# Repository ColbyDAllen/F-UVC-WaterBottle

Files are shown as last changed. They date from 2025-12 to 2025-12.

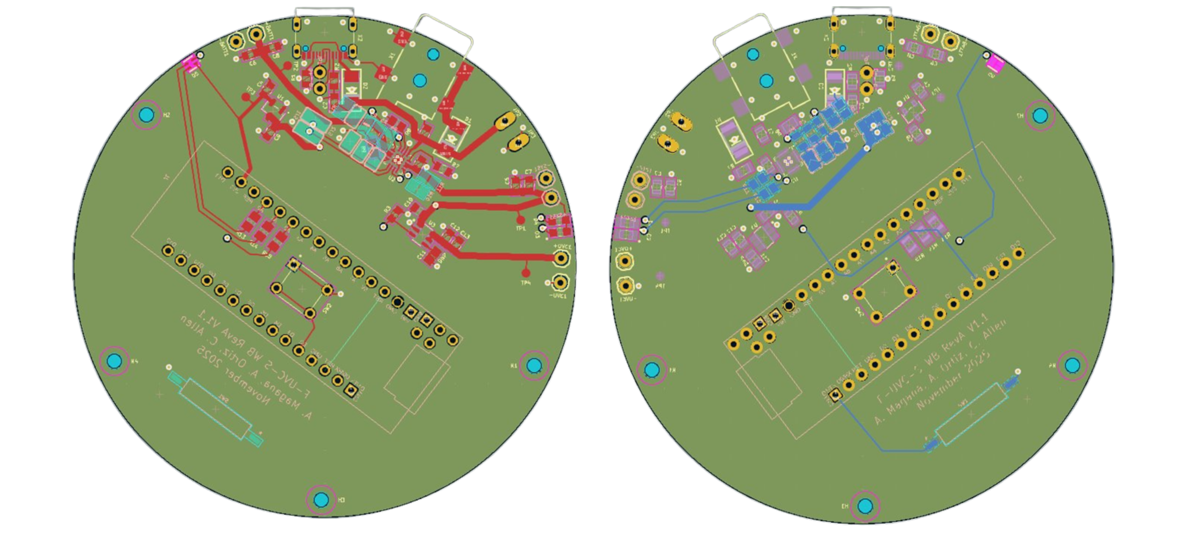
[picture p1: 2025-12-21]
Hardware/ECAD_v2/PCB_2D_ECAD.png

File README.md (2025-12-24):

# F-UVC-WaterBottle (Prototype)

**F-UVC-WaterBottle** is a prototype for a **portable, bottle-scale water treatment concept** that stages:

1. **Filtration** to handle turbidity and many dissolved contaminants, then  
2. **UVC LED exposure** to target microorganisms in the treated volume.

The current repo centers on **STM32 firmware** and a **lid PCB** that controls a gated UVC branch, backed by early **MCAD** for a two-chamber bottle (Outer dirty shell + inner filtered/UVC chamber) and a refillable filter cartridge.

> ⚠️ **Safety / Disclaimer**
>
> - This is **not** a certified disinfection device and **not** a minimum viable / usable product.  
> - **UVC is hazardous** to eyes and skin. Misuse can cause injury.  
> - Current printed parts are **not food-safe** and **not reliably watertight**.  
> - Battery-powered systems can fail dangerously if miswired (overcurrent, shorts, thermal runaway).  
> - This project exists for **engineering documentation and learning only**.  
>   **Do not rely on it for drinking water.**

---

## What this project is trying to explore

**User story (Target scenario)**

> “As someone who travels, camps, or works where tap water isn’t always viable,  
> I need a compact bottle that can handle **turbidity, taste, and biological contamination**,  
> so I can safely drink without hauling single-use filters, chemicals, or a stove.”

Rather than choosing **filtration *or* UVC**, this prototype explores a **staged approach** inspired by:

- **Press-to-filter systems** (e.g. Grayl GeoPress) for **multi-barrier filtration**, and  
- **Cap-integrated UVC** (e.g. Larq PureVis 2) for **in-bottle optical disinfection**.

The long-term research question is:  

Can a bottle-scale system combine **filter-first** architecture with **geometry-aware UVC dosing** and still be **usable** (Cycle times, charging, cleaning, and cost)?

For the full background, math, and validation plan, see the accompanying [project write-up](https://colbydanielallen.com/portfolio/filtration-uvc-water-bottle/).

---

## Repository layout

- **/Software/** – STM32L031 firmware project (STM32CubeIDE)  
- **/Hardware/** – hardware artifacts  
  - **/Hardware/ECAD/** – KiCad PCB files for the lid/control board (power path, MCU, interlocks, UVC gating)  
  - **/Hardware/MCAD/** – SolidWorks models & STEP files for the bottle's inner chamber, outer chamber, lid, and filter cartridge  
- **/Docs/** *(planned)* – validation notes, test logs, and design references

---

## System overview

### Functional architecture

**Treatment path**

1. **Outer chamber (Dirty water)**  
   - Filled from the source (Tap, stream, questionable faucet).  
   - Houses a **threaded, refillable filter cartridge**.

2. **Filter cartridge (FairCap-inspired)**  
   - Printable shell intended to be packed with **cotton + activated carbon + media**.  
   - Goal: Reduce particulates, some metals/organics, and improve UV transmittance (UVT).

3. **Inner chamber (Filtered water)**  
   - Receives water through the filter cartridge.  
   - Interior will be designed to be **reflective** and geometrically favorable for UVC dose delivery.

4. **Lid UVC subsystem**  
   - Contains **UVC LED + driver**, **charger/power-path board**, **MCU**, **load switch**, **reed switch**, and **status LED(s)**.  
   - UVC LED shines through a **small UVC-transmissive window** into the inner chamber.

**Electronics & control**

- **Li-ion battery** + **BQ24074-class charger** for USB/DC/solar input and load sharing.  
- **3.3 V rail** for logic (STM32L031K6).  
- **High-side load switch** for the UVC branch (Gated by MCU and interlocks).  
- **Single push button** for cycle control.  
- **RGB LED** for state indication.  
- **Reed switch + magnet** for lid-closed detection (firmware + hardware gating).

---

## Hardware stack

### MCAD (Bottle chambers, lid, and filter)

The MCAD branch (SolidWorks) currently includes:

- **Outer chamber**: Holds untreated water.  
- **Inner chamber**: Receives filtered water and forms the UVC treatment volume.  
- **Filter cartridge**: A threaded, refillable block inspired by FairCap, intended to be packed with media (cotton + activated carbon + salt, etc.).  
- **Lid**: Houses the electronics, UVC lens/window, RGB light pipes, and reed-switch magnet pocket.

**Status / caveats**

- Current prints are **PETG** and intended as **“looks-like” prototypes only**.  
- Magnet pocket and wall thickness are still being refined (Early prints exposed the magnet cavity into the threads).  
- Future revisions will move away from epoxy and toward **M2 fasteners and gaskets** for serviceability and sealing.  
- Long-term, a **metal inner chamber** (Steel) would be preferable for UVC compatibility and cleanliness.

### ECAD (Lid PCB, rev A)

The ECAD branch uses **KiCad** and currently implements:

- **Power path & charging**
  - **BQ24074-class charger** (Adafruit reference design)  
  - Input: **USB-C or solar (5-10 V)**  
  - Load sharing (Run from input while charging battery)  
  - Input dynamic power management to avoid solar brown-out  
  - Status: **PGOOD**, **CHG** exposed for future MCU use

- **Logic rail**
  - **MCP1700** 3.3 V LDO (or similar) from charger **SYS/OUT** rail  
  - Local decoupling and layout tuned for stability

- **UVC branch gating**
  - **TPS22918** high-side load switch
  - VIN from SYS rail, VOUT to UVC driver module  
  - MCU-controlled **EN**, default-OFF on reset/boot  
  - Optional CT pin for soft-start (In-rush shaping)

- **MCU & I/O**
  - **STM32L031K6**: Initially hosted on a **NUCLEO-L031K6** dev board, with the custom PCB providing power and I/O connectivity.  
  - **Reed switch**: Input for lid-closed detection.  
  - **Single user button**: User input.  
  - **RGB LED** (tri-color, PWM-driven): For state indication.

A separate constant-current UVC LED board (i.e. **IO Rodeo 275nm module**) currently handles LED drive. In future revisions its topology could be folded into a dedicated UVC daughterboard or an integrated lid PCB.

---

## Firmware: STM32L031K6

Firmware lives under **`/Software/`** and targets **STM32L031K6Tx**, typically on a **NUCLEO-L031K6** for bring-up.

### High-level behavior

- **Gated UVC branch**
  - Controls the UVC load-switch **EN** line.  
  - **OFF by default** at boot/reset.  
  - Forced OFF on:
    - lid-open (reed switch)  
    - cycle cancel  
    - (future) fault conditions

- **Cycle selection (single button)**
  - **Single tap** → short cycle (~1 minute), LED **amber** (R+G).  
  - **Double tap** (within ~400 ms) → long cycle (~3 minutes), LED **blue**.  
  - **Tap during an active cycle** → cancel cycle, force UVC OFF, return to idle.

- **Reed-switch safety**
  - Input is configured with pull-up:
    - **LOW → lid closed / magnet present (safe)**  
    - **HIGH → lid open (unsafe → force UVC OFF)**  
  - If lid opens during a cycle:
    - UVC branch is shut off immediately.  
    - State machine resets (no lingering taps or modes).  
    - LED returns to idle (off).

- **Auto-stop**
  - Each cycle tracks a target end-time.  
  - At expiry, UVC branch = OFF, mode cleared, LED back to idle.

### I/O mapping (expected)

**Inputs**

- `REED_SW_Pin` – reed switch (input with pull-up).  
- `B2_Pin` – user button (EXTI, falling-edge, active-low).

**Outputs**

- `Control_Pin` – UVC load-switch enable:  
  - LOW → UVC branch OFF  
  - HIGH → UVC branch ON
- RGB LED via **TIM2 PWM** channels (common-anode assumed):
  - `PA3` → TIM2 CH4 → RED  
  - `PA1` → TIM2 CH2 → GREEN  
  - `PA0` → TIM2 CH1 → BLUE

Some SPI/OLED-related pins may remain configured from CubeMX templates. They’re reserved for future debug UI and don’t affect UVC logic.

---

## Build & flash (STM32CubeIDE)

- **Toolchain:** STM32CubeIDE 
- **Target MCU:** STM32L031K6Tx

1. Clone the repository.
2. Open **STM32CubeIDE** → **File → Import… → Existing Projects into Workspace…**.
3. Select the firmware project under `/Software/`.
4. Build the **Debug** or **Release** configuration.
5. Connect **ST-LINK** (NUCLEO onboard or external).
6. Click **Run** or **Debug** to flash.

After flashing, for bench testing:

- Power the board from a **regulated 3.3 V rail** (or the NUCLEO’s default power path).  
- Connect the reed switch, button, RGB LED, and load-switch control line as per the I/O mapping.  
- Confirm that behavior matches the “High-level behavior” section above using a **safe stand-in load** (e.g. an OLED display or resistor) instead of a UVC LED.

---

## Validation status (UVC effectiveness)

A detailed **biodosimetry-based validation plan** is drafted (MS2 coliphage, collimated-beam-derived k(λ), RED/VF framework, EPA 186 mJ/cm² target), but:

> 🔬 **No biological tests have been executed yet.**  
> No log-reduction claims are made for this prototype.

Until validation is complete:

- All cycle times, UX modes, and design equations should be treated as **engineering placeholders**, not safety guarantees.  
- Any use of this design with real water is strictly **at your own risk** and **strongly discouraged**.

---
## Sponsorship (PCB fabrication)

<p align="center">
  PCBWay Sponsorship
</p>

F-UVC cap PCB – top side

PCB fabrication for this prototype was kindly sponsored by
[PCBWay](https://www.pcbway.com/), who covered the cost of the
4-layer boards and DHL shipping via store credit.

From a bring-up perspective the experience was exactly what I was hoping for:

- The 4-layer FR-4 S1000H TG150 stack-up (78 × 78 mm, 1.6 mm, ENIG, 1 oz Cu inner/outer)
  matched the KiCad design with no surprises.
- Drill hits, solder mask, and silkscreen registration were all on-point; pads were fully
  exposed and silkscreen stayed off fine-pitch pads.
- ENIG pads wetted cleanly during hot-air/QFN reflow, and the USB-C, BQ24074, and header
  footprints all fit mechanically without any bodge-wires or footprint hacks.

This repository and write-up reflect my own design decisions, testing, and documentation.
Sponsorship support did not include editorial control or performance claims; any results
here are based on my own prototyping and are shared for transparency and learning.

---

## Roadmap / next steps (WIP)

Planned expansions to this repo:

- **ECAD**
  - Integrate or document a dedicated UVC LED + heatsink board.  
  - Tighten power-integrity checks (inrush, brownout behavior, EMC, thermal).

- **MCAD**
  - Add outer bottle, finalized filter cartridge, and realistic sealing strategy (O-rings, glands/grooves, fasteners).  
  - Explore food-safe materials (Metal inner chamber, UVC-stable windows, and gaskets).

- **Firmware**
  - Add explicit **fault/error states** (Blink codes, fault latch, charging/solar status UI).  
  - Integrate charger status (PGOOD / CHG) into UX.

- **Testing & validation**
  - Execute **UVC biodosimetry tests** and publish RED / DVal results.  
  - Map measured performance back into Design Equations 1 & 2 to tune cycle times and power.

---

## License

MIT License — see `LICENSE`.

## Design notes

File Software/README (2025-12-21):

This firmware is part of a UVC water disinfection prototype. 

UVC light can be hazardous to skin and eyes. 

Do not operate any UVC LEDs without proper enclosure, shielding, and safety testing. 

This code is provided for educational and prototyping purposes only.

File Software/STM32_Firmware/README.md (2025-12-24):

# F-UVC Water Bottle – STM32L031 Firmware

Firmware for a prototype UVC water bottle controller built around an **STM32L031K6** MCU (typically on a **NUCLEO-L031K6** dev board or an equivalent custom PCB).

> ⚠️ **Safety warning – read first**
>
> - This firmware is part of a **UV-C water disinfection prototype**.
> - UV-C is hazardous to **eyes and skin**.
> - Do **not** power any UV-C LEDs without a proper enclosure, interlocks, and safety testing.
> - This code is provided for **educational and prototyping** purposes only. Do **not** rely on it to produce safe drinking water.

---

## Behavior (user-facing)

The firmware implements a simple tap-based UI and a lid interlock:

- **Single tap** on the button  
  - Starts a **short UV-C cycle (~1 minute)**  
  - UV-C load switch is **enabled**  
  - RGB status LED shows **amber** (R + G)

- **Double tap** (two taps within ~400 ms)  
  - Starts a **long UV-C cycle (~3 minutes)**  
  - UV-C load switch is **enabled**  
  - RGB status LED shows **blue**

- **Tap during an active cycle**  
  - **Cancels** the current cycle immediately  
  - UV-C load switch turns **OFF**  
  - RGB LED returns to **idle (off)**

- **Lid safety (reed switch interlock)**  
  - Reed switch is wired so **LOW = lid closed / magnet present (safe)**  
  - **HIGH = lid open (unsafe)**  
  - If the firmware ever detects **lid open** while a cycle is active, it will:
    - Turn the UV-C load switch **OFF**
    - **Abort** the running cycle
    - Clear any pending tap state
    - Block new cycles until the lid is closed again (reed back LOW)

---

## Hardware assumptions (logical)

This firmware expects a hardware stack roughly matching:

- **MCU**: STM32L031K6 (NUCLEO-L031K6 or equivalent custom board)
- **UV-C branch**: UV-C LED driver powered through a **high-side load switch**
- **Lid interlock**: **reed switch + magnet** detecting lid-closed state
- **UI**:  
  - 1 × **momentary push button** (active-low, interrupt-driven)  
  - 1 × **RGB LED** driven from TIM2 PWM channels

Exact pin names (e.g., `REED_SW_Pin`, `B2_Pin`, `Control_Pin`, RGB LED pins) are defined in the CubeMX-generated project and should be kept in sync with your hardware.

---

## Build & flash (STM32CubeIDE)

**Toolchain:** STM32CubeIDE  
**Target:** STM32L031K6Tx

1. Clone the repository and navigate to the `Software/` directory.
2. In **STM32CubeIDE**, go to  
   `File → Import… → Existing Projects into Workspace…`
3. Select the `Software` folder (or the STM32 project folder inside it) as the **root directory**.
4. Import the project and build the **Debug** (or **Release**) configuration.
5. Connect a **NUCLEO-L031K6** (onboard ST-LINK) or an external ST-LINK to your custom board.
6. Use the provided **Debug/Run configuration** (or create your own) to flash the firmware.

This project uses the **STM32 HAL** and the CubeMX-generated linker script  
`STM32L031K6TX_FLASH.ld`.

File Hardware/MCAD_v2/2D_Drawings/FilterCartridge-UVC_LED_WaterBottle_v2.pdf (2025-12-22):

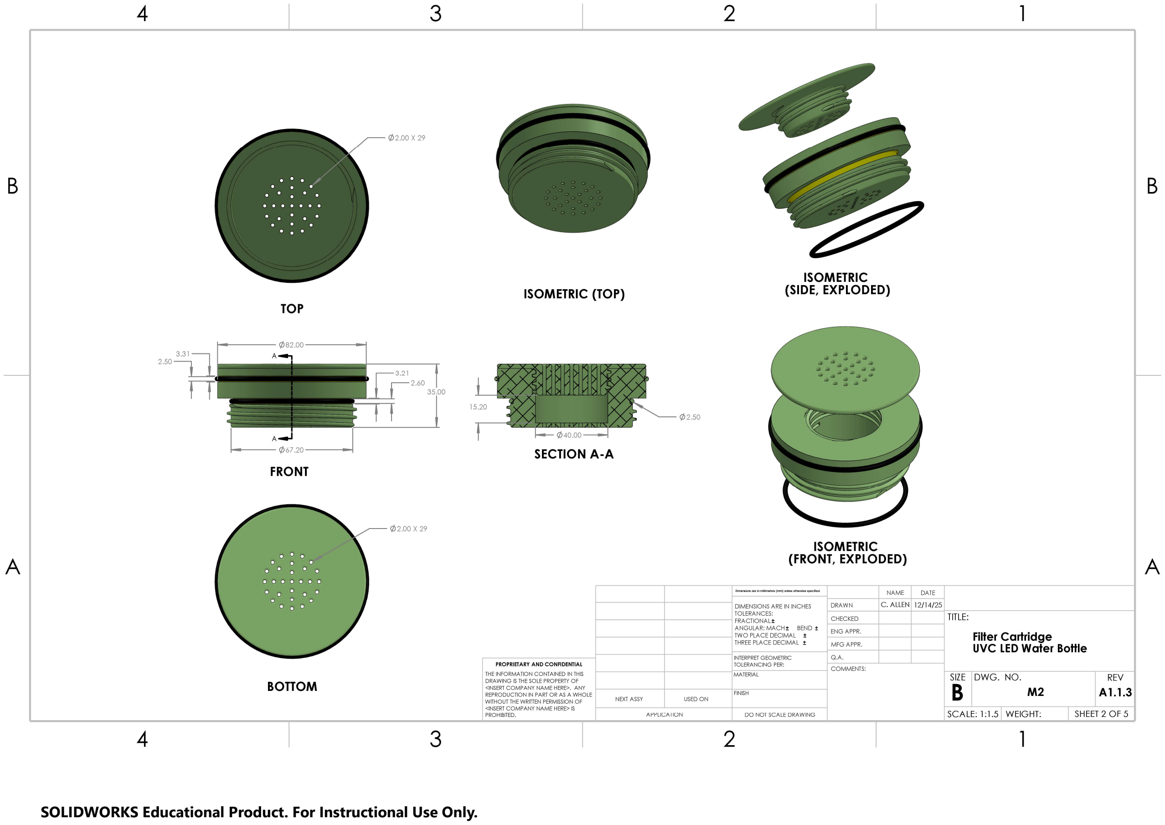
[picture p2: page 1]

SOLIDWORKS Educational Product. For Instructional Use Only.

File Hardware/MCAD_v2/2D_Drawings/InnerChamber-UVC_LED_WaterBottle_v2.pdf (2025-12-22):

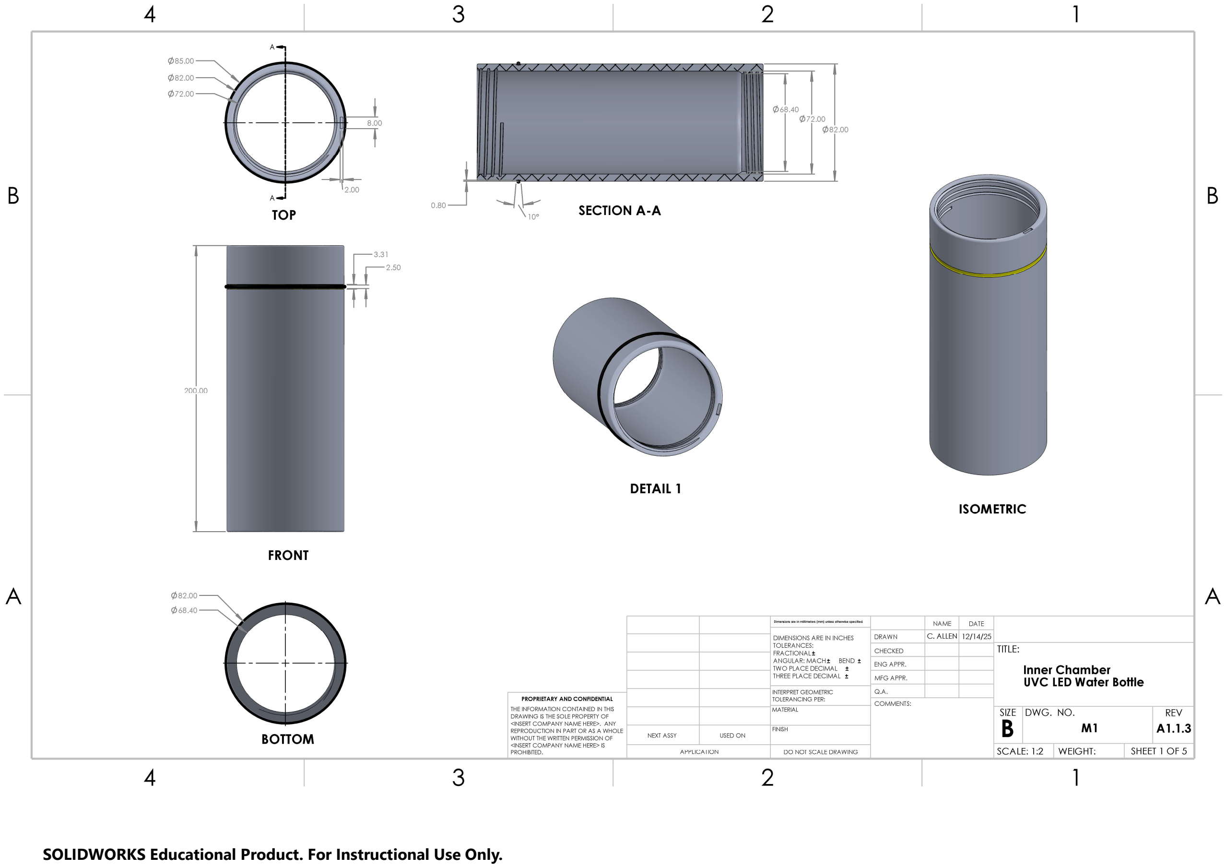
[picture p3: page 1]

SOLIDWORKS Educational Product. For Instructional Use Only.

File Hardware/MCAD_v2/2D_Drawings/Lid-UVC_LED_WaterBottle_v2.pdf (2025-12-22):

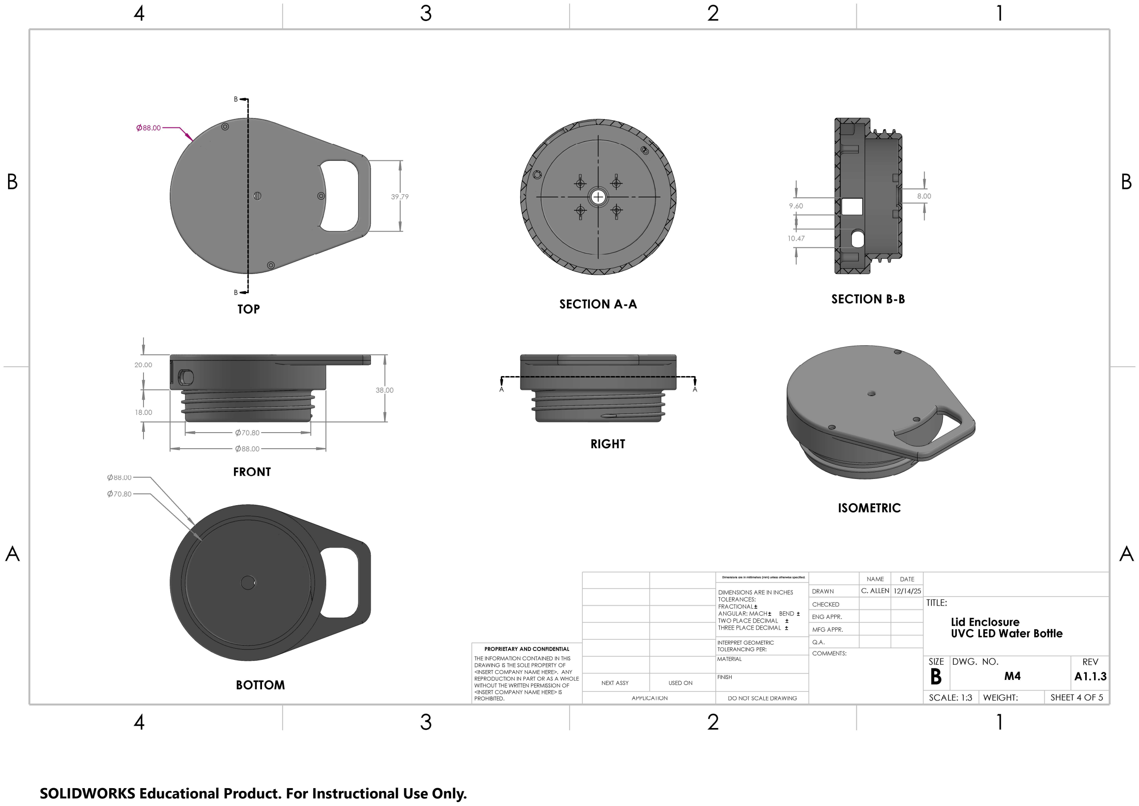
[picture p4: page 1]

SOLIDWORKS Educational Product. For Instructional Use Only.

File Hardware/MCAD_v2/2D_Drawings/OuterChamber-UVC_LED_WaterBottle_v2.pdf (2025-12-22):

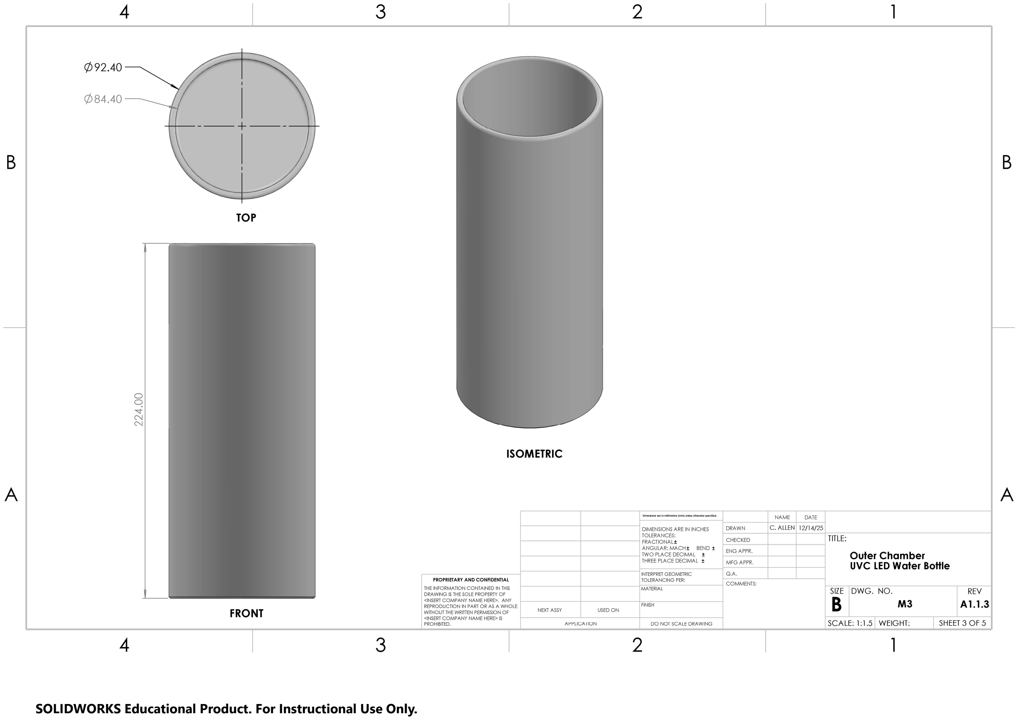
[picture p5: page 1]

SOLIDWORKS Educational Product. For Instructional Use Only.

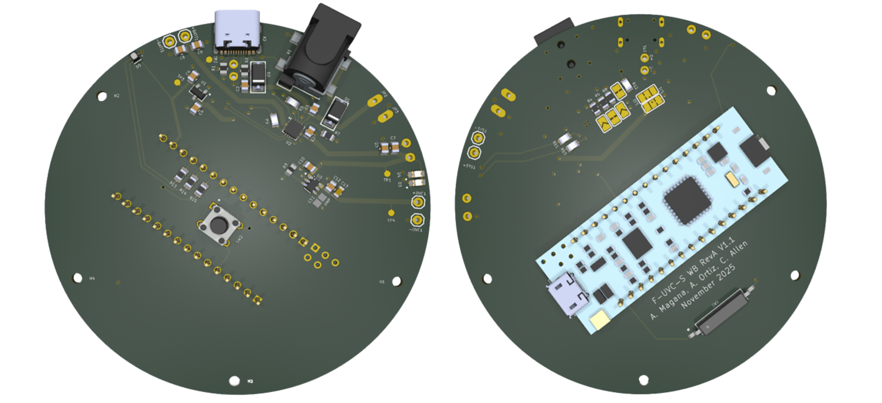
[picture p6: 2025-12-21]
Hardware/ECAD_v2/PCB_3D_ECAD.png

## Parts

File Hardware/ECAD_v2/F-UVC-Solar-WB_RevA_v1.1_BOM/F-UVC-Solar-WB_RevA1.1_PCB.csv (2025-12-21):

Id | Designator | Footprint | Quantity | Designation | Supplier and ref
1 | R9,R8,R12,R10,R11 | RES_10k_0805 | 5 | 10K
2 | R15,R14,R13 | RES_2.2K_0805 | 3 | 2.2K
3 | D2,D1 | SMADIODE | 2 | SK34A
4 | SW2 | SW_Push_6mm_Tall_SW_TS02-66-100-BK-260-LCR-D | 1 | TS02-66-100-BK-260-LCR-D
5 | U2 | BQ24074_QFN16_3MM | 1 | BQ24074
6 | -UVC1,+BATT1,+UVC1,-BATT1,-SYS1,+SYS1 | 1X01_BatteryTerminal_HandSolder | 6 | ~
7 | R7,R5 | RES_1k_0805 | 2 | 1K
8 | C9,C3,C7,C5,C1,C4,C6,C2,C8 | CAP_10uF_0805(CAP_CL21_SAM) | 9 | 10 uF
9 | JP1 | 1X02_ROUND | 1 | HEADER-1X2ROUND
10 | D5 | LED_RGB_DIFFUSED_0606_150161M153130 | 1 | LED_RGB_DIFFUSED_0606_150161M153130
11 | U3 | TPS22918TDBVRQ1_SOT95P280X145-6N | 1 | TPS22918TDBVRQ1
12 | C11 | CAP_470pF_0805 | 1 | 470 pF
13 | R3 | RES_100k_0805(RC0805N_PAN) | 1 | 100K
14 | TP3 | TestPoint_PAD.03X.05 | 1 | +3V3(TP)
15 | X2 | USB_C_CUSB31-CFM2AX-01-X | 1 | USB Type C
16 | C10 | CAP_1uF_0805 | 1 | 10 uF
17 | U1 | MCP1700T_3302E_TT(SOT-23_MC_MCH( | 1 | MCP1700T-3302E/TT
18 | TP1 | TestPoint_PAD.03X.05 | 1 | OUT(TP)
19 | C12 | CAP_10uF_0805(CAP_CL21_SAM) | 1 | 1 uF
20 | X1 | DCJACK_2MM_SMT | 1 | 2.1mm DC
21 | D4 | LED_RED_0805(HSMC_C170) | 1 | RED
22 | D3 | LED_RED_0805(HSMC_C170) | 1 | GREEN
23 | JP3,JP2 | 1X01_OVAL | 2 | HEADER-1X1
24 | C13 | CAP_10uF_0805(CAP_CL21_SAM) | 1 | 0.1 uF
25 | TP2 | TestPoint_PAD.03X.05 | 1 | VLIPO(TP)
26 | R2,R1 | RES_5.1k_0805 | 2 | 5.1K
27 | TP4 | TestPoint_PAD.03X.05 | 1 | VLOAD(TP)
28 | UNK1A1,THERM1 | SOLDERJUMPER_CLOSEDWIRE | 2 | SOLDERJUMPERCLOSED
29 | R6 | RES_2k_0603 | 1 | 2k
30 | UNK0.5A1,UNK1.5A1 | SOLDERJUMPER_ARROW_NOPASTE | 2 | SOLDERJUMPER
31 | SW1 | ReedSwitch_CT10-1530-G1 | 1 | SW_Reed
32 | SJ1,SJ2 | SOLDERJUMPER_2WAY_OPEN_NOPASTE | 2 | ~
33 | R4 | RES_590_0805 | 1 | 590
34 | J1 | NUCLEO-L031K6 | 1 | Header 15X1_male

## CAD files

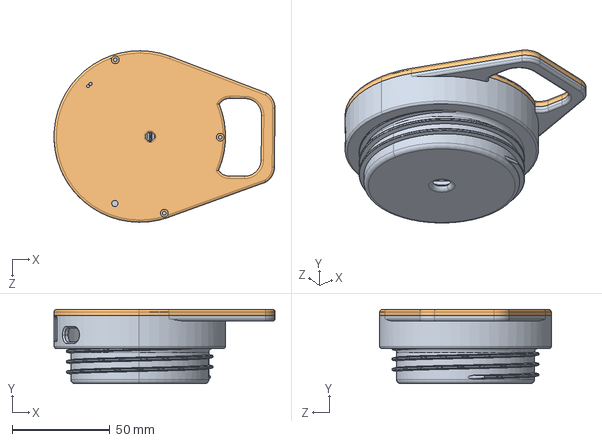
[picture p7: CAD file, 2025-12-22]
Hardware/MCAD_v2/Print_Files/Lid-UVC_LED_WaterBottle_v2.STEP
113.3 x 38.0 x 88.0 mm

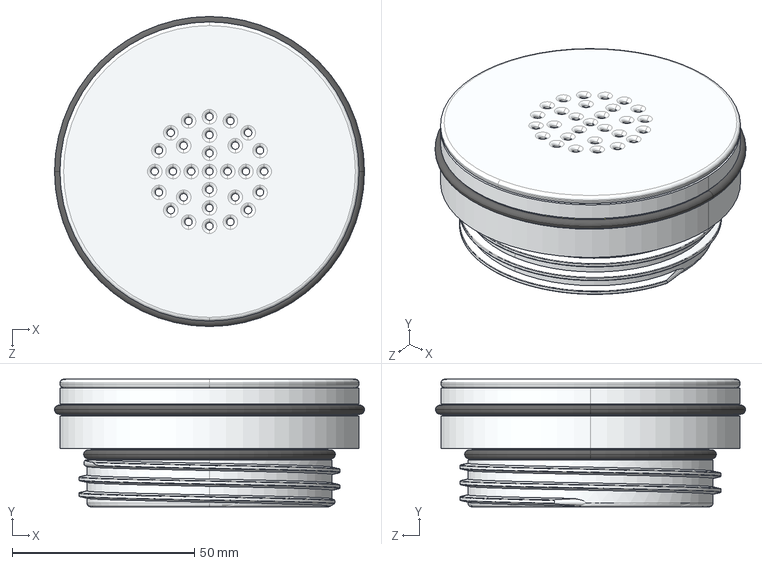
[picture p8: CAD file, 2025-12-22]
Hardware/MCAD_v2/Print_Files/FilterCartidge-UVC_LED_WaterBottle_v2.STEP
85.0 x 35.0 x 85.0 mm

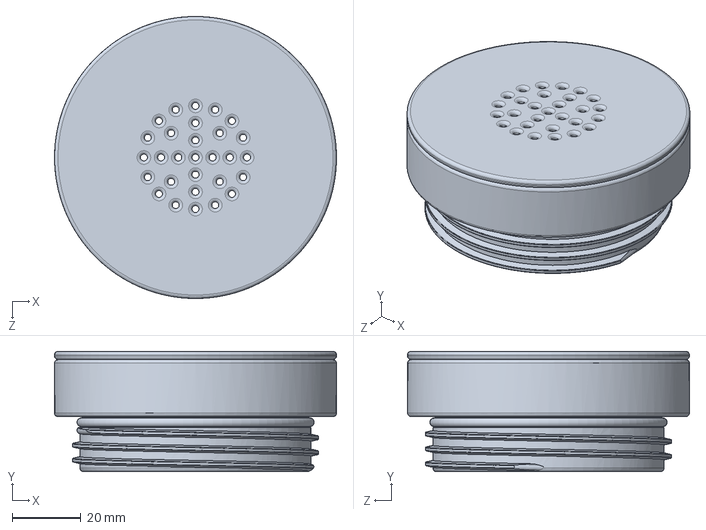
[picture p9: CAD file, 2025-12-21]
Hardware/MCAD_v2/SolidWorks_Files/F-UVC-Solar_RevA1.1.3_FilterCartridge.SLDPRT
82.0 x 35.0 x 82.0 mm

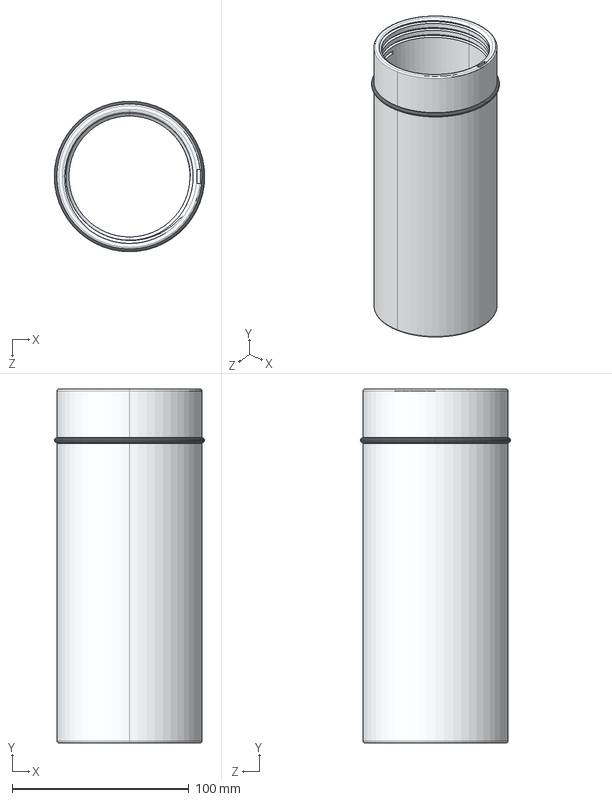
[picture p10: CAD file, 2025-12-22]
Hardware/MCAD_v2/Print_Files/InnerChamber-UVC_LED_WaterBottle_v2.STEP
85.0 x 200.0 x 85.0 mm

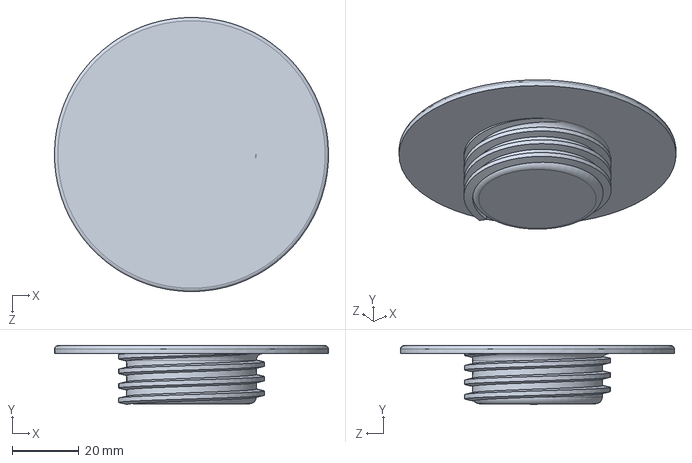
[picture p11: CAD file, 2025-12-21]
Hardware/MCAD_v2/SolidWorks_Files/F-UVC-Solar_RevA1.1.3_FilterCartridgeBottom_COMBINE.SLDPRT
82.0 x 17.7 x 82.0 mm

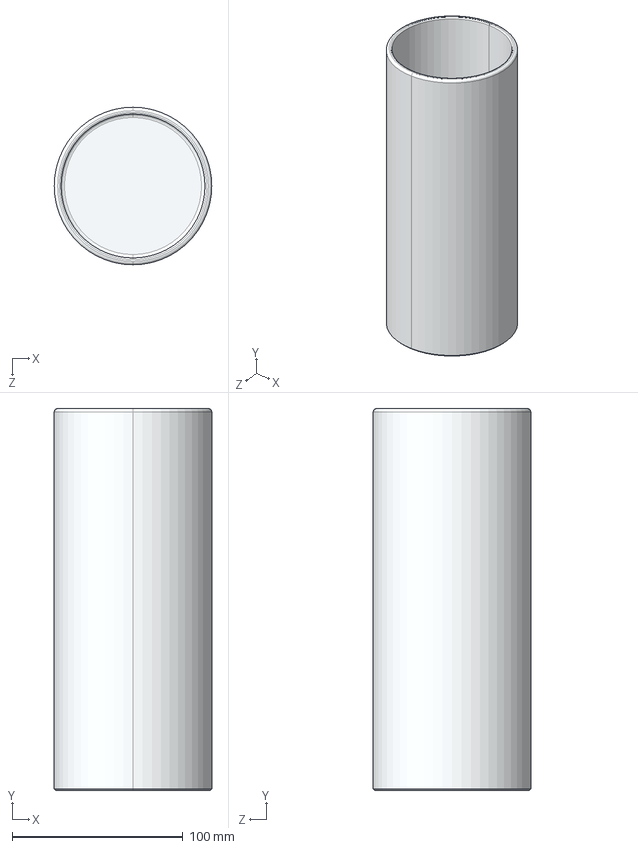
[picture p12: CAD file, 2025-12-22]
Hardware/MCAD_v2/Print_Files/OuterChamber-UVC_LED_WaterBottle_v2.STEP
92.4 x 224.0 x 92.4 mm

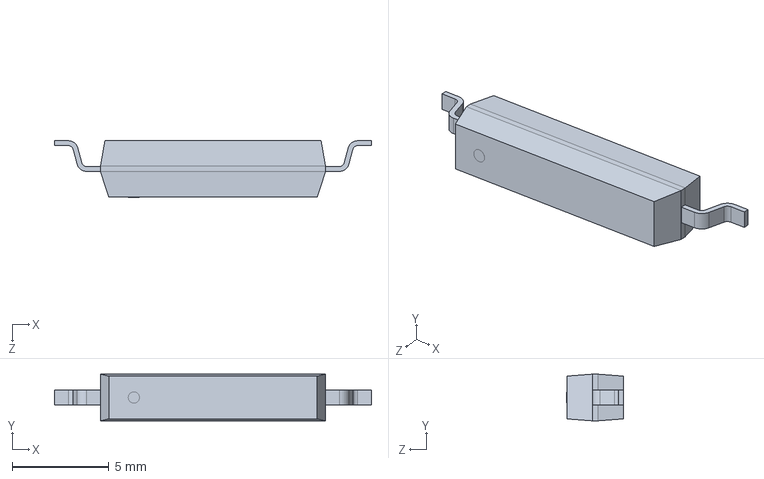
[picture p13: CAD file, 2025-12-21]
Hardware/MCAD_v2/SolidWorks_Files/SW_CT10-xxxx-G1_COT_2.SLDPRT
16.4 x 2.41 x 2.92 mm

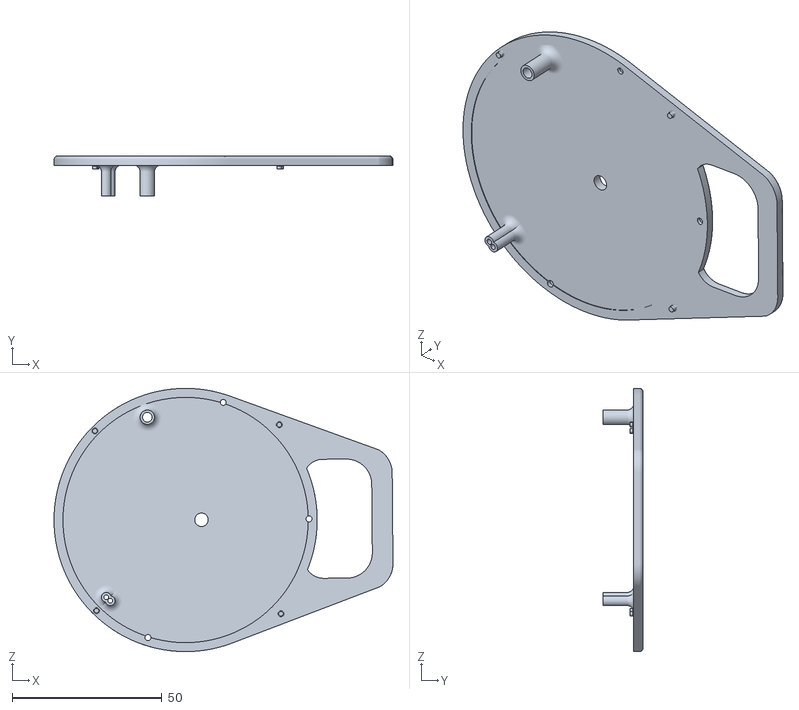
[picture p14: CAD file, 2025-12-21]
Hardware/MCAD_v2/Print_Files/LidTop-UVC_LED_WaterBottle_v2.STL
113.3 x 13.4 x 88.0

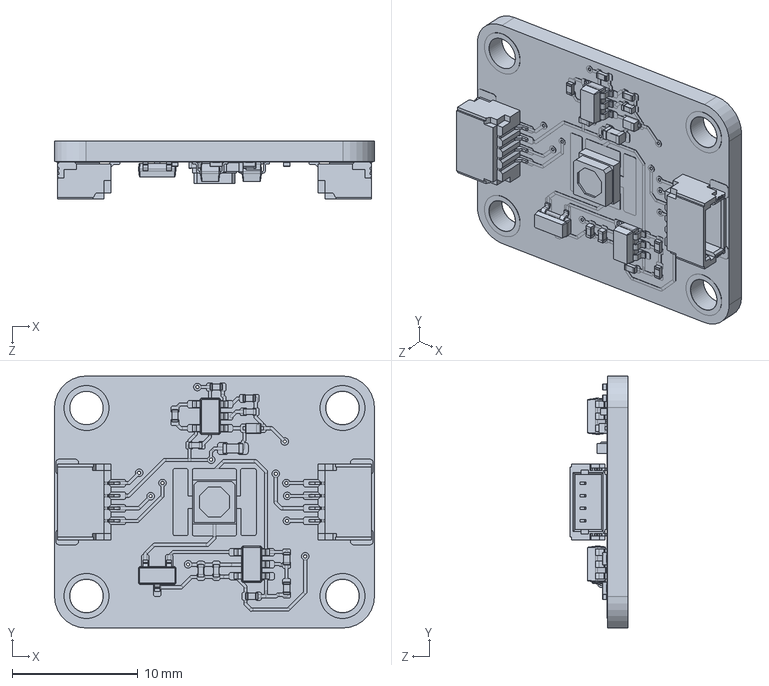
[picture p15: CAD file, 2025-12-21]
Hardware/MCAD_v2/SolidWorks_Files/275nm_SU_CULBN2_24mA_2.SLDPRT
25.4 x 20.0 x 4.64 mm

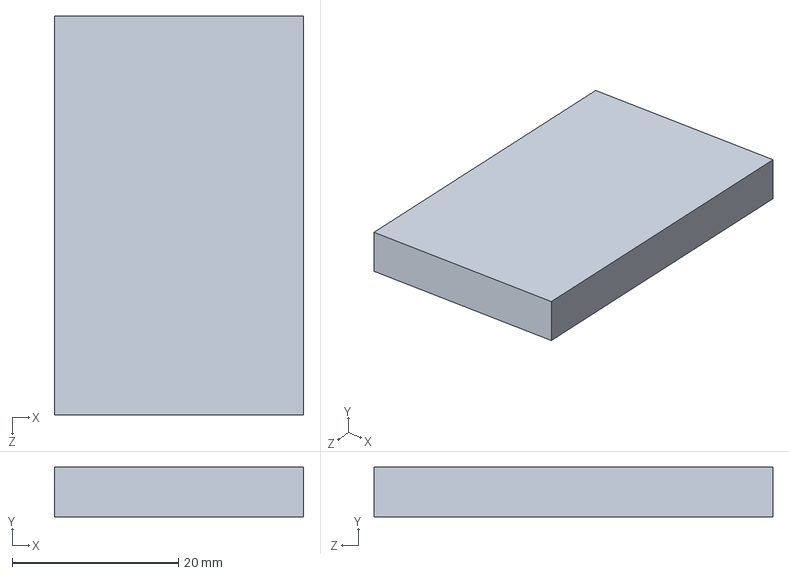
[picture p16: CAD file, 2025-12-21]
Hardware/MCAD_v2/SolidWorks_Files/850mAh,3.7v_2.SLDPRT
30.0 x 6.00 x 48.0 mm

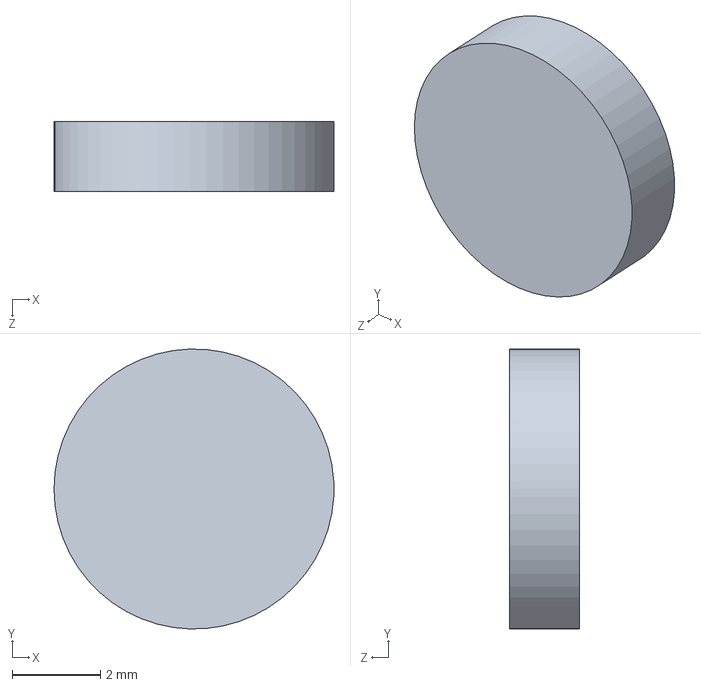
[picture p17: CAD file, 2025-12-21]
Hardware/MCAD_v2/SolidWorks_Files/Neodymium Iron Boron Magnet_2.SLDPRT
6.35 x 6.35 x 1.59 mm

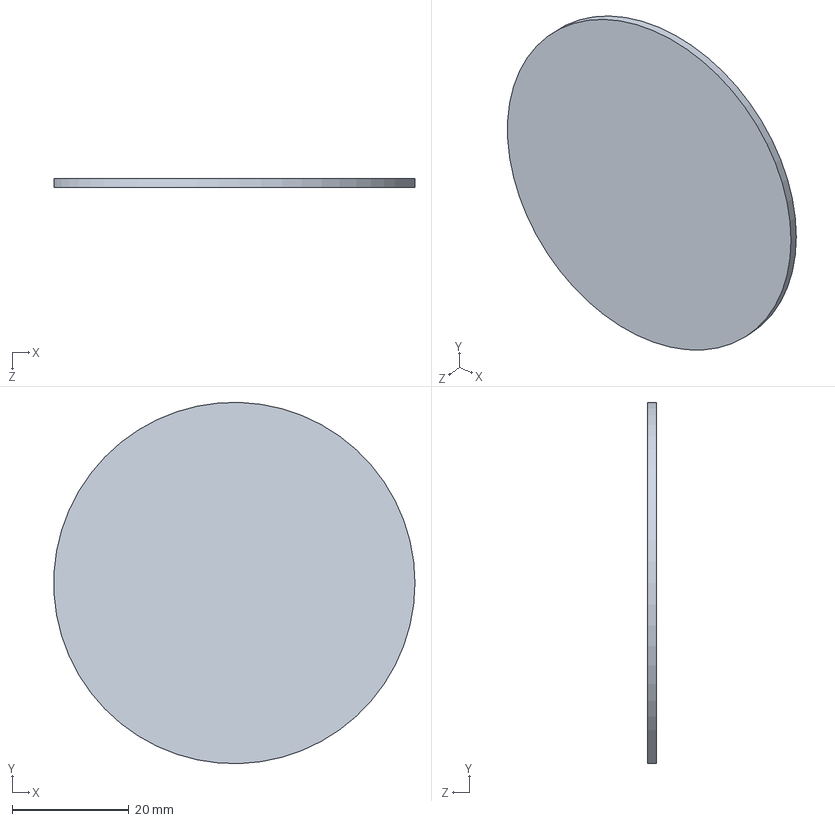
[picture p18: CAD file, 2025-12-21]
Hardware/MCAD_v2/SolidWorks_Files/FusedQuartzSilicaSaphire_2.SLDPRT
61.9 x 62.0 x 1.50 mm

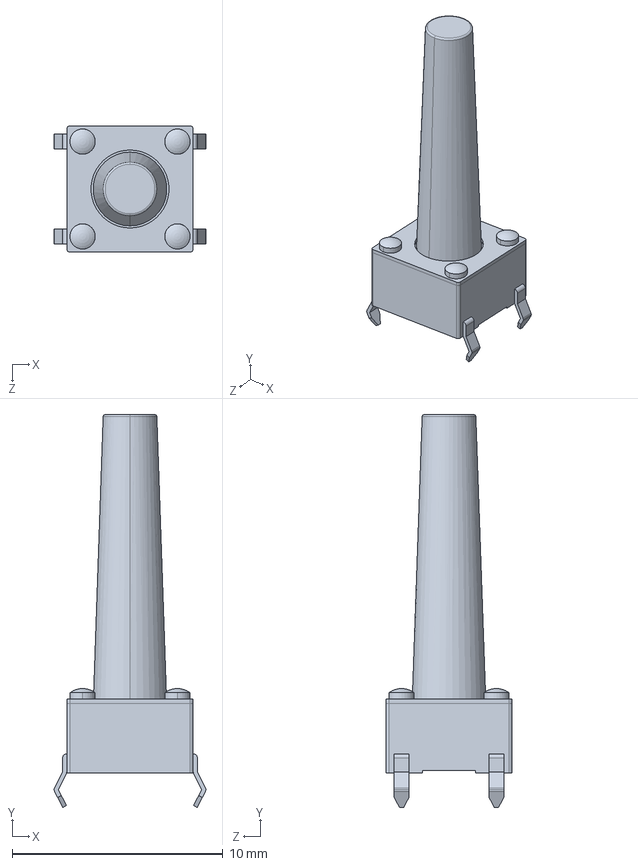
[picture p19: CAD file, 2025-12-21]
Hardware/MCAD_v2/SolidWorks_Files/SW_Push_6x6x17mm_Taller_TS02-66-170-BK-100-SCR-D_2.SLDPRT
7.20 x 18.6 x 6.00 mm

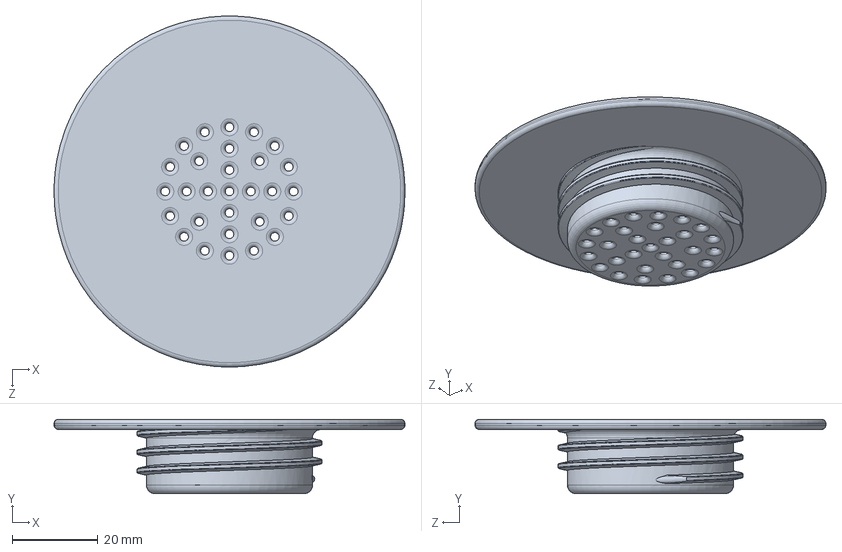
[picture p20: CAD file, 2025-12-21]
Hardware/MCAD_v2/SolidWorks_Files/F-UVC-Solar_RevA1.1.3_FilterCartridgeBottom.SLDPRT
82.0 x 17.4 x 82.0 mm

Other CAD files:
Hardware/MCAD_v2/SolidWorks_Files/F-UVC-Solar_RevA1.1.3_LidCap.SLDPRT
Hardware/MCAD_v2/SolidWorks_Files/F-UVC-Solar_RevA1.1.3_OuterBottle.SLDPRT
Hardware/MCAD_v2/SolidWorks_Files/F-UVC-Solar_RevA1.1.3_InnerBottle.SLDPRT
Hardware/MCAD_v2/SolidWorks_Files/F-UVC-Solar_RevA1.1.3_FilterCartridge_COMBINE.SLDPRT
Hardware/MCAD_v2/Print_Files/InnerChamber-UVC_LED_WaterBottle_v2.STL
Hardware/MCAD_v2/Print_Files/OuterChamber-UVC_LED_WaterBottle_v2.STL
Hardware/MCAD_v2/SolidWorks_Files/1295N489_Chemical-Resistant Viton Fluoroelastomer O-Ring.SLDPRT
Hardware/MCAD_v2/SolidWorks_Files/1295N492_Chemical-Resistant Viton Fluoroelastomer O-Ring.SLDPRT
Hardware/MCAD_v2/SolidWorks_Files/9262K943_Oil-Resistant Buna-N O-Ring.SLDPRT
Hardware/MCAD_v2/SolidWorks_Files/InnerChamber-UVC_LED_WaterBottle_v2.SLDDRW
Hardware/MCAD_v2/SolidWorks_Files/Lid-UVC_LED_WaterBottle_v2.SLDDRW
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

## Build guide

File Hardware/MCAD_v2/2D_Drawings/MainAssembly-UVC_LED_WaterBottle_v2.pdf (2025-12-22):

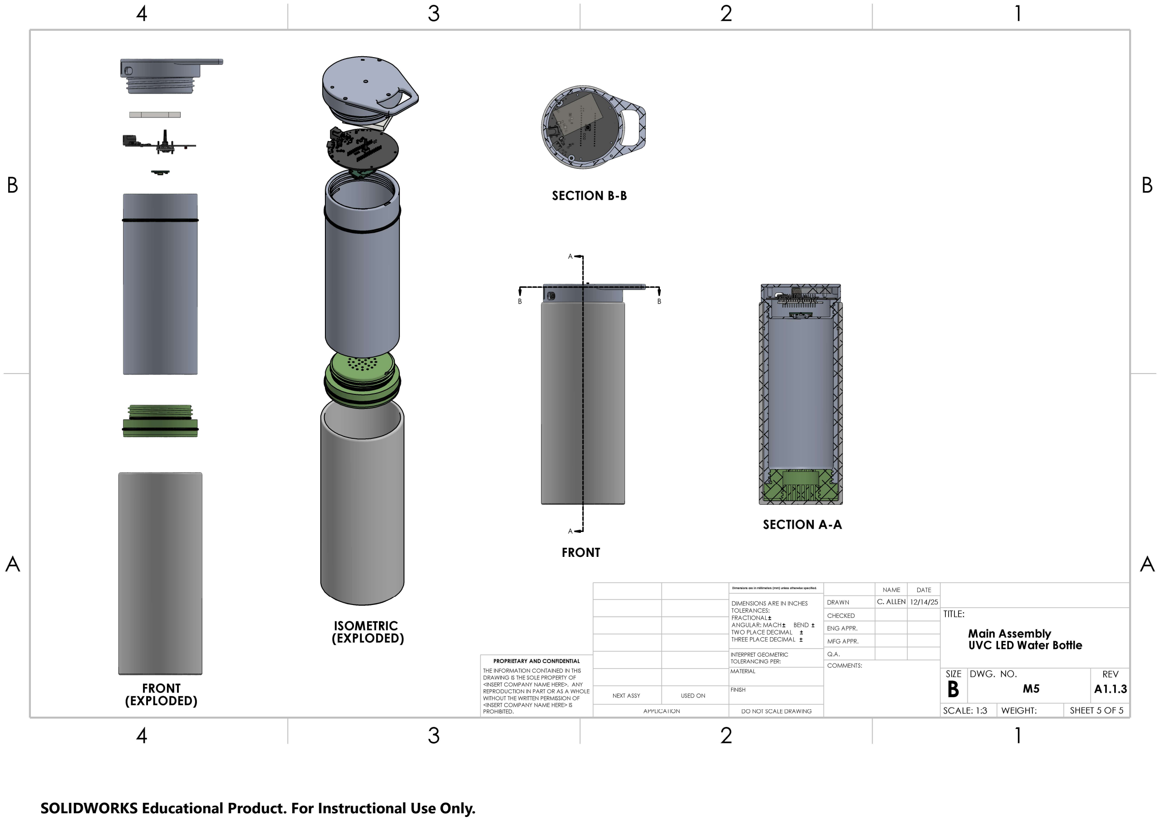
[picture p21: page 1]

SOLIDWORKS Educational Product. For Instructional Use Only.

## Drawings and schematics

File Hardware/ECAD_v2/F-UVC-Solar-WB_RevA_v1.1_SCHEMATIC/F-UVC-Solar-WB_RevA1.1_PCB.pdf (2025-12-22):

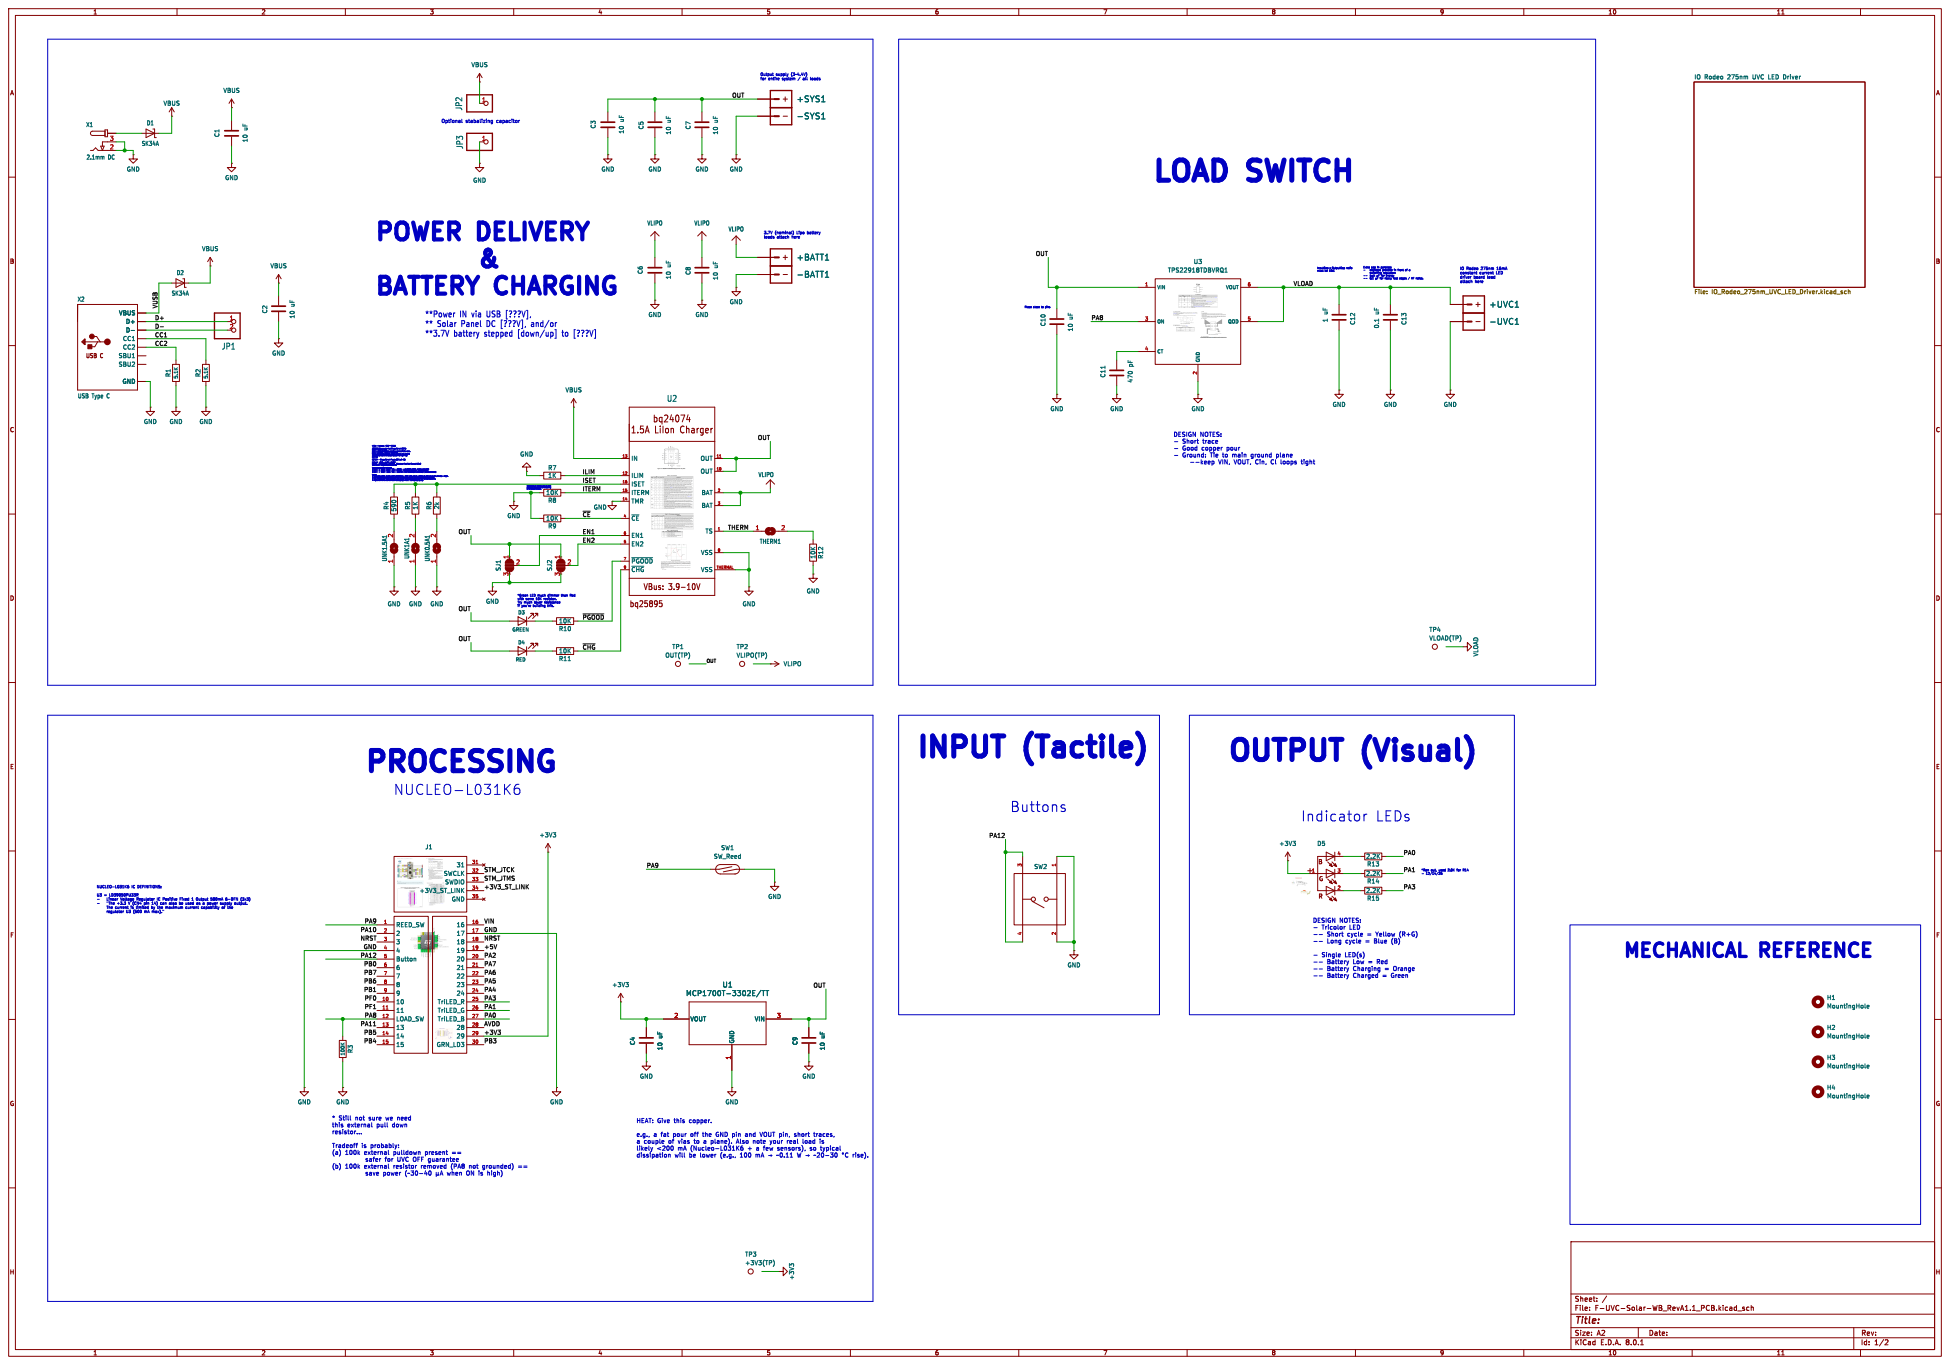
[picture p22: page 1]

IO Rodeo 275nm UVC LED Driver File: IO_Rodeo_275nm_UVC_LED_Driver.kicad_sch GND

**Power IN via USB [???V], ** Solar Panel DC [???V], and/or

3 SJ2 +3V3 C4 10 uF GND GND R3 100K VBUS GND GND

DESIGN NOTES: - Short trace
D4 RED GND

- Good copper pour
- Ground: Tie to main ground plane

DESIGN NOTES: - Tricolor LED

* Still not sure we need
resistor... Tradeoff is probably:

HEAT: Give this copper. e.g., a fat pour off the GND pin and VOUT pin, short traces, a couple of vias to a plane). Also note your real load is

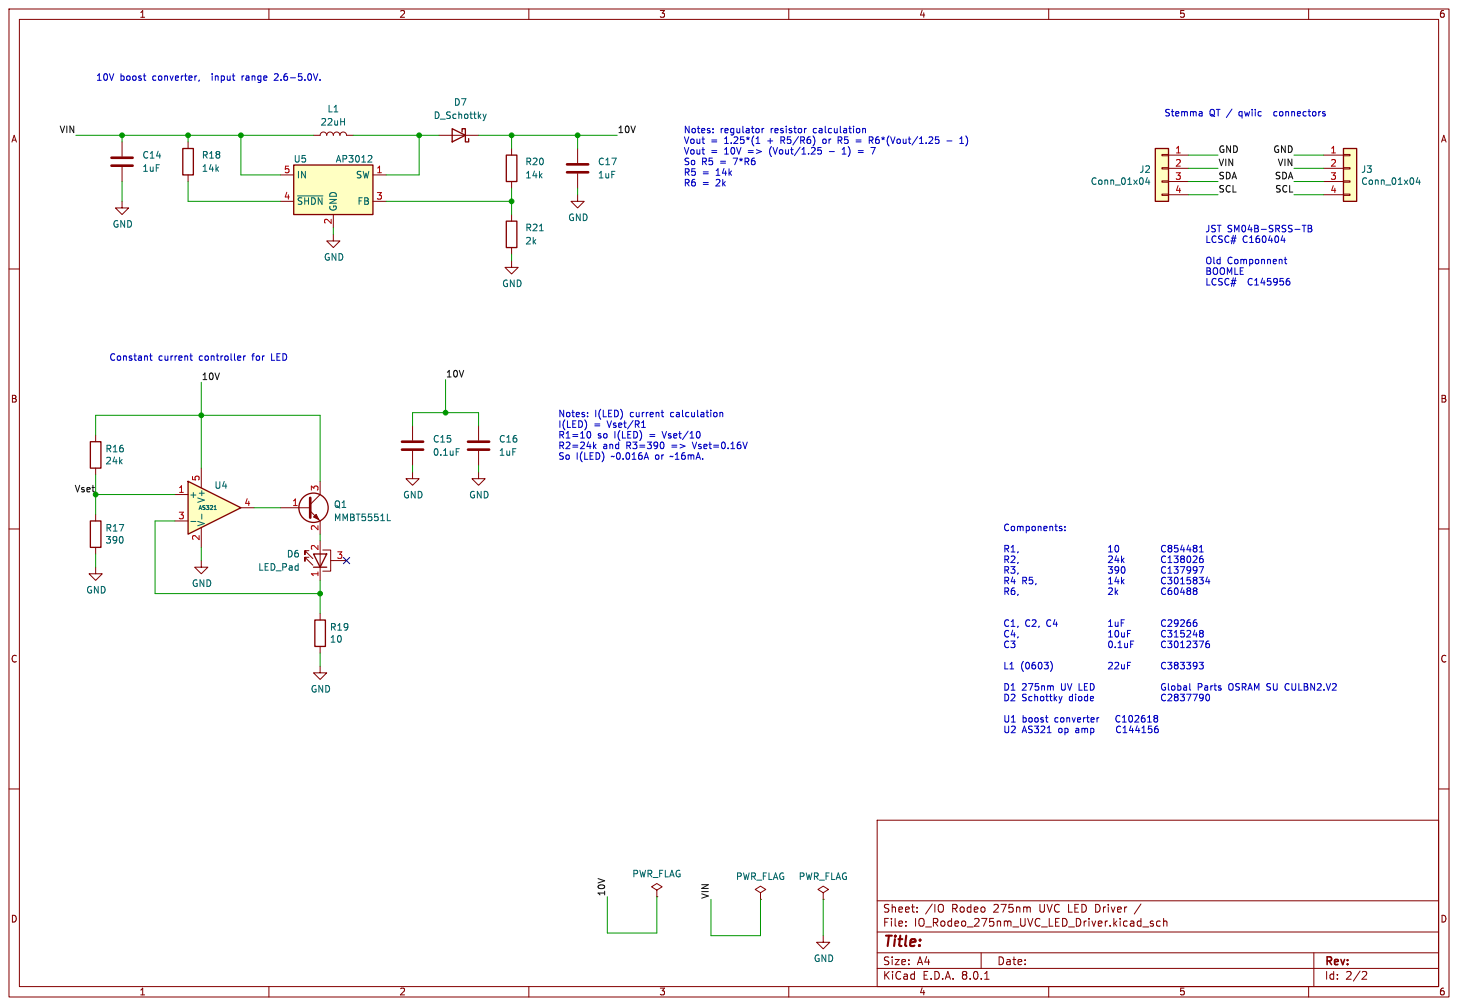
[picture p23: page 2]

JST SM04B-SRSS-TB
LCSC# C160404 Old Componnent BOOMLE

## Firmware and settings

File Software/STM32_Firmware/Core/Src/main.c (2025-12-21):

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
/* Includes ------------------------------------------------------------------*/
#include "main.h"

/* USER CODE BEGIN Includes */
#include <string.h>
/* USER CODE END Includes */

/* USER CODE BEGIN PTD */
// distinguish short vs long cycle
typedef enum
{
  LED_STATE_IDLE = 0,          // No cycle running
  LED_STATE_CYCLE_RUNNING,     // UV/cycle in progress
  LED_STATE_ERROR              // Reserved for future error/low-batt, etc.
} LedState_t;

typedef enum
{
  CYCLE_MODE_NONE = 0,
  CYCLE_MODE_SHORT,   // 1-minute (yellow)
  CYCLE_MODE_LONG     // 3-minute (blue)
} CycleMode_t;
/* USER CODE END PTD */

/* USER CODE BEGIN PD */
#define CYCLE_DURATION_SHORT_MS   (60u * 1000u)           // 1-minute cycle
#define CYCLE_DURATION_LONG_MS    (3u  * 60u * 1000u)     // 3-minute cycle
#define DOUBLE_TAP_WINDOW_MS      400u                    // max gap between taps for "double"
/* USER CODE END PD */

SPI_HandleTypeDef hspi1;

TIM_HandleTypeDef htim2;

UART_HandleTypeDef huart2;

/* USER CODE BEGIN PV */
volatile uint8_t  g_load_enabled  = 0;   // start OFF for safety
volatile uint32_t g_last_press_ms = 0;

volatile LedState_t   g_led_state    = LED_STATE_IDLE;
volatile CycleMode_t  g_cycle_mode   = CYCLE_MODE_NONE;
static   uint32_t     g_pwm_period   = 0;   // cached TIM2 ARR for LED PWM

// timing + tap tracking
volatile uint32_t g_cycle_end_ms = 0;      // when current cycle should auto-stop
volatile uint8_t  g_pending_tap  = 0;      // 1 = waiting to see if this becomes a double tap
volatile uint32_t g_first_tap_ms = 0;      // time of first tap in a potential double-tap sequence
/* USER CODE END PV */

void SystemClock_Config(void);
static void MX_GPIO_Init(void);
static void MX_USART2_UART_Init(void);
static void MX_SPI1_Init(void);
static void MX_TIM2_Init(void);
/* USER CODE BEGIN PFP */
static void RGB_Set(uint16_t r, uint16_t g, uint16_t b);
/* USER CODE END PFP */

/* USER CODE BEGIN 0 */

static void RGB_Init(void)
{
  // Cache the auto-reload value (ARR) set in MX_TIM2_Init (999 in your config)
  g_pwm_period = __HAL_TIM_GET_AUTORELOAD(&htim2);

  // Start PWM on all three channels
  HAL_TIM_PWM_Start(&htim2, TIM_CHANNEL_1);
  HAL_TIM_PWM_Start(&htim2, TIM_CHANNEL_2);
  HAL_TIM_PWM_Start(&htim2, TIM_CHANNEL_4);

  // Ensure LED is fully OFF (brightness = 0 → CCR = 0 → output HIGH all the time)
  RGB_Set(0, 0, 0);
}

// brightness arguments are 0..g_pwm_period
//   0   = OFF
//   max = brightest
static void RGB_Set(uint16_t r, uint16_t g, uint16_t b)
{
  if (r > g_pwm_period) r = g_pwm_period;
  if (g > g_pwm_period) g = g_pwm_period;
  if (b > g_pwm_period) b = g_pwm_period;

  // Common-anode LED, active-low PWM:
  //   - TIM2 CH4 (PA3) → RED
  //   - TIM2 CH2 (PA1) → GREEN
  //   - TIM2 CH1 (PA0) → BLUE
  //
  // With PWM1 + OCPOLARITY_LOW:
  //   CCR = 0            → output HIGH 100% → LED OFF
  //   CCR > 0            → output LOW for (CCR/ARR) → LED ON fractionally
  //   CCR = g_pwm_period → ~full brightness
  __HAL_TIM_SET_COMPARE(&htim2, TIM_CHANNEL_4, r); // RED
  __HAL_TIM_SET_COMPARE(&htim2, TIM_CHANNEL_2, g); // GREEN
  __HAL_TIM_SET_COMPARE(&htim2, TIM_CHANNEL_1, b); // BLUE
}

// Map logical LED states to actual RGB colors
static void LED_ApplyState(void)
{
  uint16_t r = 0, g = 0, b = 0;
  uint16_t mid = g_pwm_period / 2;  // ~50% brightness

  switch (g_led_state)
  {
    case LED_STATE_IDLE:
      r = g = b = 0;           // OFF
      break;

    case LED_STATE_CYCLE_RUNNING:
      if (g_cycle_mode == CYCLE_MODE_LONG)
      {
        // Long cycle (3 min) → BLUE
        r = 0;
        g = 0;
        b = (g_pwm_period * 3) / 4;     // ~75% blue
      }
      else
      {
        // Short cycle (1 min) → warm amber
        r = (g_pwm_period * 3)    / 4;   //  ~75% of full scale
        g = (g_pwm_period * 3)    / 16;  //  ~18–20% of full scale
        b = 0;
      }
      break;

    case LED_STATE_ERROR:
    default:
      r = mid; g = 0; b = 0;   // RED
      break;
  }

  RGB_Set(r, g, b);
}

/* USER CODE END 0 */

/**
  * @brief  The application entry point.
  * @retval int
  */
int main(void)
{

  /* MCU Configuration--------------------------------------------------------*/

  /* Reset of all peripherals, Initializes the Flash interface and the Systick. */
  HAL_Init();

  /* Configure the system clock */
  SystemClock_Config();

  /* Initialize all configured peripherals */
  MX_GPIO_Init();
  MX_USART2_UART_Init();
  MX_SPI1_Init();
  MX_TIM2_Init();
  /* USER CODE BEGIN 2 */

  // Ensure load is OFF at boot for safety (TPS22918 ON low)
  g_load_enabled  = 0;
  g_cycle_mode   = CYCLE_MODE_NONE;
  g_cycle_end_ms = 0;
  g_pending_tap  = 0;
  HAL_GPIO_WritePin(Control_GPIO_Port, Control_Pin, GPIO_PIN_RESET);

  // Initialize RGB status LED (TIM2 PWM on PA0/PA1/PA3)
  RGB_Init();
  g_led_state = LED_STATE_IDLE;
  LED_ApplyState();

  const uint16_t frame_delay_ms = 100; // reused as active-loop delay

  /* USER CODE END 2 */

  /* Infinite loop */
  /* USER CODE BEGIN WHILE */
  while (1)
  {
    // Reed safety: if reed opens, force load OFF
    GPIO_PinState reed_state = HAL_GPIO_ReadPin(REED_SW_GPIO_Port, REED_SW_Pin);
    uint8_t reed_closed      = (reed_state == GPIO_PIN_RESET); // LOW = closed, magnet present

    if (!reed_closed && g_load_enabled)
    {
      g_load_enabled = 0;
      g_cycle_mode   = CYCLE_MODE_NONE;   // clear cycle mode on unsafe
      g_pending_tap  = 0;                 // clear pending tap
      HAL_GPIO_WritePin(Control_GPIO_Port, Control_Pin, GPIO_PIN_RESET);
    }

    // Promote a single tap to a short cycle if no second tap arrived
    if (!g_load_enabled && g_pending_tap)
    {
      uint32_t now_ms = HAL_GetTick();

      if ((now_ms - g_first_tap_ms) > DOUBLE_TAP_WINDOW_MS)
      {
        g_pending_tap  = 0;
        g_cycle_mode   = CYCLE_MODE_SHORT;
        g_load_enabled = 1;
        g_cycle_end_ms = now_ms + CYCLE_DURATION_SHORT_MS;

        HAL_GPIO_WritePin(Control_GPIO_Port, Control_Pin, GPIO_PIN_SET);
      }
    }

    // Update RGB LED state based on current system condition
    if (g_load_enabled && reed_closed)
    {
      // Cycle in progress → yellow/blue by mode
      if (g_led_state != LED_STATE_CYCLE_RUNNING)
      {
        g_led_state = LED_STATE_CYCLE_RUNNING;
        LED_ApplyState();
      }
    }
    else
    {
      // No cycle / unsafe → idle (off, for now)
      if (g_led_state != LED_STATE_IDLE)
      {
        g_led_state = LED_STATE_IDLE;
        LED_ApplyState();
      }
    }

    // Auto-stop when cycle time is over
    if (g_load_enabled)
    {
      uint32_t now_ms = HAL_GetTick();
      if ((g_cycle_mode != CYCLE_MODE_NONE) && (now_ms >= g_cycle_end_ms))
      {
        g_load_enabled = 0;
        g_cycle_mode   = CYCLE_MODE_NONE;
        g_pending_tap  = 0;   // no tap pending after a finished cycle
        HAL_GPIO_WritePin(Control_GPIO_Port, Control_Pin, GPIO_PIN_RESET);
        // LED will fall back to IDLE on next loop iteration
      }

      // While active, delay at the same rate we used for the animation
      HAL_Delay(frame_delay_ms);
    }
    else
    {
      // Load is off
      HAL_Delay(10);
    }
    /* USER CODE END WHILE */

    /* USER CODE BEGIN 3 */
  }
  /* USER CODE END 3 */
}

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
/* USER CODE BEGIN 4 */

void HAL_GPIO_EXTI_Callback(uint16_t GPIO_Pin)
{
  if (GPIO_Pin == B2_Pin)  // user button interrupt
  {
    uint32_t now = HAL_GetTick();

    // Simple debounce: ignore events within 250 ms
    if ((now - g_last_press_ms) < 250)
    {
      return;
    }
    g_last_press_ms = now;

    // Read reed: LOW = closed (magnet present, safe)
    GPIO_PinState reed_state = HAL_GPIO_ReadPin(REED_SW_GPIO_Port, REED_SW_Pin);
    uint8_t reed_closed      = (reed_state == GPIO_PIN_RESET);

    // If reed is open (unsafe), force load OFF and ignore "turn on" requests
    if (!reed_closed)
    {
      g_load_enabled = 0;
      g_cycle_mode   = CYCLE_MODE_NONE;
      g_pending_tap  = 0;
      HAL_GPIO_WritePin(Control_GPIO_Port, Control_Pin, GPIO_PIN_RESET);
      return;
    }

    // If a cycle is currently running, treat this tap as "cancel"
    if (g_load_enabled)
    {
      g_load_enabled = 0;
      g_cycle_mode   = CYCLE_MODE_NONE;
      g_pending_tap  = 0;

      HAL_GPIO_WritePin(Control_GPIO_Port, Control_Pin, GPIO_PIN_RESET);
      return;
    }

    // No cycle running here → handle single vs double tap

    if (!g_pending_tap)
    {
      // First tap: start the double-tap window
      g_pending_tap  = 1;
      g_first_tap_ms = now;
    }
    else
    {
      // Second tap within the window?
      if ((now - g_first_tap_ms) <= DOUBLE_TAP_WINDOW_MS)
      {
        // Recognize as double tap → start LONG (3-minute) cycle immediately
        g_pending_tap  = 0;
        g_cycle_mode   = CYCLE_MODE_LONG;
        g_load_enabled = 1;
        g_cycle_end_ms = now + CYCLE_DURATION_LONG_MS;

        HAL_GPIO_WritePin(Control_GPIO_Port, Control_Pin, GPIO_PIN_SET);
      }
      else
      {
        // Too slow; treat this tap as a new "first tap"
        g_first_tap_ms = now;
        // g_pending_tap stays 1
      }
    }
  }
}

/* USER CODE END 4 */
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


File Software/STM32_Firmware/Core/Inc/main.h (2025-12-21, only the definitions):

#define TriLED_B_Pin GPIO_PIN_0
#define TriLED_B_GPIO_Port GPIOA
#define TriLED_G_Pin GPIO_PIN_1
#define TriLED_G_GPIO_Port GPIOA
#define VCP_TX_Pin GPIO_PIN_2
#define VCP_TX_GPIO_Port GPIOA
#define TriLED_R_Pin GPIO_PIN_3
#define TriLED_R_GPIO_Port GPIOA
#define RST_Pin GPIO_PIN_4
#define RST_GPIO_Port GPIOA
#define DC_Pin GPIO_PIN_0
#define DC_GPIO_Port GPIOB
#define Control_Pin GPIO_PIN_8
#define Control_GPIO_Port GPIOA
#define REED_SW_Pin GPIO_PIN_9
#define REED_SW_GPIO_Port GPIOA
#define CS_Pin GPIO_PIN_11
#define CS_GPIO_Port GPIOA
#define B2_Pin GPIO_PIN_12
#define B2_GPIO_Port GPIOA
#define B2_EXTI_IRQn EXTI4_15_IRQn
#define TMS_Pin GPIO_PIN_13
#define TMS_GPIO_Port GPIOA
#define TCK_Pin GPIO_PIN_14
#define TCK_GPIO_Port GPIOA
#define VCP_RX_Pin GPIO_PIN_15
#define VCP_RX_GPIO_Port GPIOA

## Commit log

2025-12-21 Add STM32L031 firmware project under Software/
2025-12-21 Rename Hardware/MCAD_v2/1295N489_Chemical-Resistant Viton Fluoroelastomer O-Ring.SLDPRT to Hardware/MCAD_v2/SolidWorks_Files/1295N489_Chemical-Resistant Viton Fluoroelastomer O-Ring.SLDPRT
    [1295N489_Chemical-Resistant Viton Fluoroelastomer O-Ring.SLDPRT]
2025-12-22 Revise PCB sponsorship information in README
    Updated sponsorship section with new sponsorship details and image.
2025-12-24 Remove PCB fabrication sponsorship details
    Removed detailed sponsorship and fabrication experience section from the README.
2025-12-24 Update PCB images in README
    Removed old PCB images and replaced with a new image link.

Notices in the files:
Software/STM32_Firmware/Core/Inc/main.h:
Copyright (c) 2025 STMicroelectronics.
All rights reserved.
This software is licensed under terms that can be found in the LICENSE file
